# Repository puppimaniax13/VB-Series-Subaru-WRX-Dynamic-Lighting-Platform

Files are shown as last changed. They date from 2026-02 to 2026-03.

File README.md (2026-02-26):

# 2022+ Subaru WRX Dynamic LED Reflector Platform

Project Header

A full-stack hardware and software solution to replace static OEM rear reflectors with addressable, reactive LED modules. This project features a modular PCB designed for the VB chassis but adaptable to any 12V automotive lighting application.

## 🚀 Technical Overview
- **Mechanical:** Custom 3D-printed housings (Fusion 360) designed for OEM fitment.
- **Electrical:** Dual-layer custom PCB (KiCad) with 12V->5V buck regulation and signal filtering.
- **Software:** C++ Firmware (Arduino) utilizing **FastLED** for sequential animations and interrupt-driven brake logic.

## 🛠️ Hardware Stack
- **MCU:** ESP-32-S3-WROOM
- **LEDs:** WS2812B Addressable Strips
- **Design Tools:** KiCad 9.0, Autodesk Fusion 360, Adobe Lightroom (Documentation)
- **3D Printer:** Bambu Labs P1S, PLA & PETG

## 📂 Repository Structure
- `/Firmware`: Arduino source code (.ino)
- `/Hardware`: KiCad project files & PCB Schematics
- `/Mechanical`: .3mf files for printing
- `/Media`: High-res project photography

## 🖨️ 3D Printing
- When using the provided *.3mf* files please try not to adjust much.
- The filament used for the lens is as follows
  - Overture Transparent PETG
  - Bambu Translucent Grey PETG
  - Overture Transparent Red PETG

## ⚖️ License
Code/Firmware: This project is licensed under the **GNU GPLv3**. You are free to use and modify it, but any derivative works must also be open-sourced under the same license.

Hardware & Design (PCB/3D Models): Licensed under CC BY-NC-SA 4.0. Personal use is encouraged; commercial use or resale of these designs is strictly prohibited without prior authorization.

*Commercial use or resale of these designs is strictly prohibited.*

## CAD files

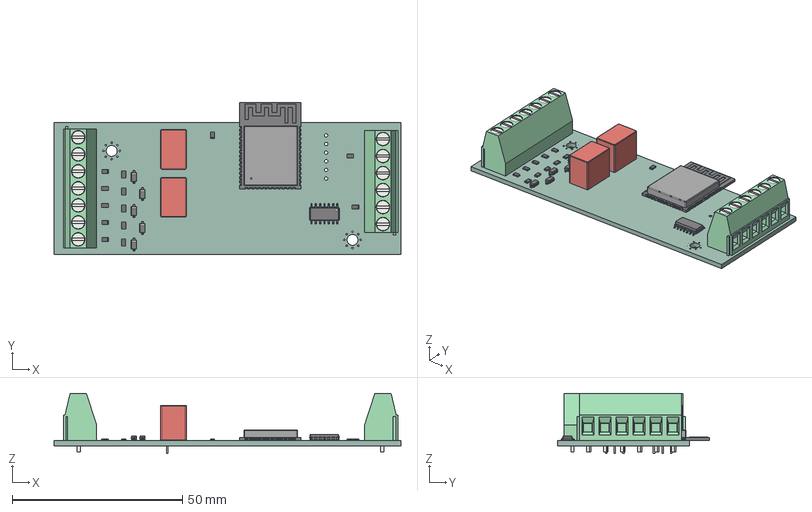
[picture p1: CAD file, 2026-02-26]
Hardware/CarLEDHub/CarLEDHub.step
102.0 x 44.7 x 17.7 mm
R_0805_2012Metric x 13
D_SOD-123 x 5
TerminalBlock_Phoenix_MKDS-1,5-6_1x06_P5.00mm_Horizontal
Converter_DCDC_TRACO_TSR-1_THT x 2
TerminalBlock_Phoenix_MKDS-1,5-7_1x07_P5.00mm_Horizontal
ESP32-S3-WROOM-1
SOIC-14_3.9x8.7mm_P1.27mm
CarLEDHub_PCB

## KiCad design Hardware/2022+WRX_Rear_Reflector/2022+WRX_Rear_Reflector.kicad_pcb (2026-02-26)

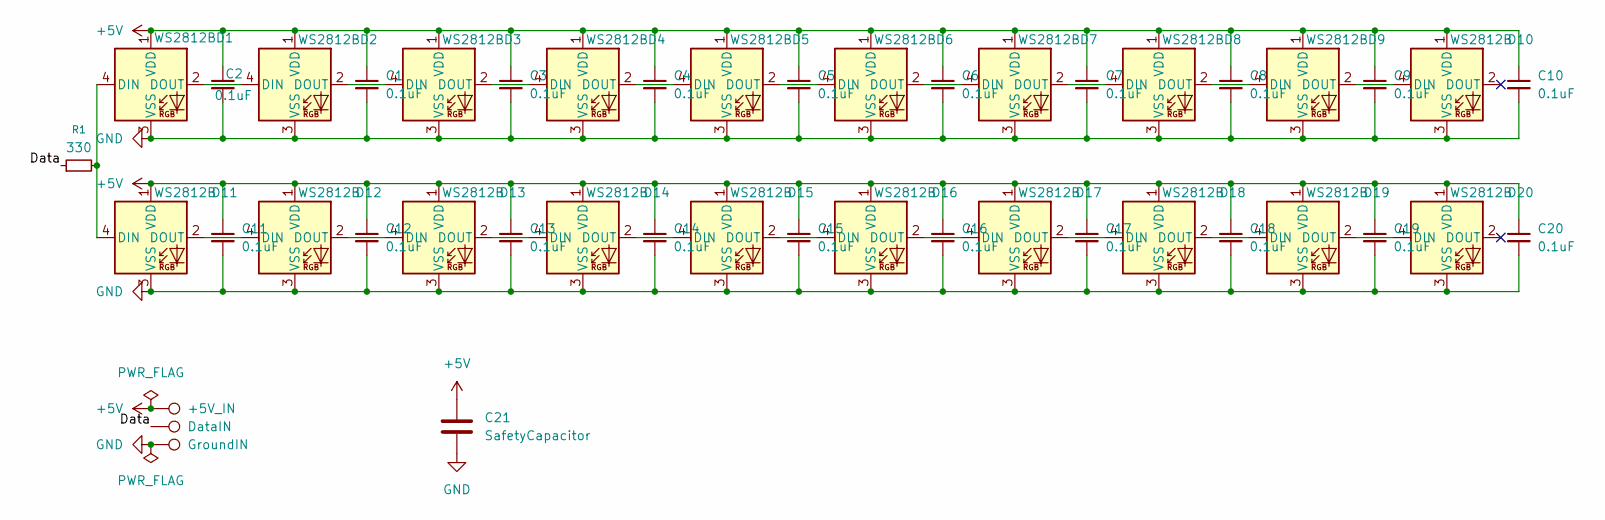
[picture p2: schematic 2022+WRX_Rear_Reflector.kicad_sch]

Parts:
C1, C2, C3, C4, C5, C6, C7, C8, C9, C10, C11, C12, C13, C14, C15, C16, C17, C18, C19, C20: 0.1uF; C_0504_1310Metric
C21: SafetyCapacitor; C_1206_3216Metric
D1, D2, D3, D4, D5, D6, D7, D8, D9, D10, D11, D12, D13, D14, D15, D16, D17, D18, D19, D20: WS2812B; LED_WS2812B_PLCC4_5.0x5.0mm_P3.2mm
R1: 330; R_0603_1608Metric
TP1: GroundIN; TestPoint_THTPad_D1.5mm_Drill0.7mm
TP2: DataIN; TestPoint_THTPad_D1.5mm_Drill0.7mm
TP3: +5V_IN; TestPoint_THTPad_D1.5mm_Drill0.7mm

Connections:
+5V: C1.1, C2.1, C3.1, C4.1, C5.1, C6.1, C7.1, C8.1, C9.1, C10.1, C11.1, C12.1, C13.1, C14.1, C15.1, C16.1, C17.1, C18.1, C19.1, C20.1, C21.1, D1.1 (VDD), D2.1 (VDD), D3.1 (VDD), D4.1 (VDD), D5.1 (VDD), D6.1 (VDD), D7.1 (VDD), D8.1 (VDD), D9.1 (VDD), D10.1 (VDD), D11.1 (VDD), D12.1 (VDD), D13.1 (VDD), D14.1 (VDD), D15.1 (VDD), D16.1 (VDD), D17.1 (VDD), D18.1 (VDD), D19.1 (VDD), D20.1 (VDD), TP3.1; also elsewhere on the board
/Data: R1.1, TP2.1; also elsewhere on the board
GND: C1.2, C2.2, C3.2, C4.2, C5.2, C6.2, C7.2, C8.2, C9.2, C10.2, C11.2, C12.2, C13.2, C14.2, C15.2, C16.2, C17.2, C18.2, C19.2, C20.2, C21.2, D1.3 (VSS), D2.3 (VSS), D3.3 (VSS), D4.3 (VSS), D5.3 (VSS), D6.3 (VSS), D7.3 (VSS), D8.3 (VSS), D9.3 (VSS), D10.3 (VSS), D11.3 (VSS), D12.3 (VSS), D13.3 (VSS), D14.3 (VSS), D15.3 (VSS), D16.3 (VSS), D17.3 (VSS), D18.3 (VSS), D19.3 (VSS), D20.3 (VSS), TP1.1; also elsewhere on the board
unnamed: D1.4 (DIN), D11.4 (DIN), R1.2
unnamed: D1.2 (DOUT), D2.4 (DIN)
unnamed: D2.2 (DOUT), D3.4 (DIN)
unnamed: D3.2 (DOUT), D4.4 (DIN)
unnamed: D4.2 (DOUT), D5.4 (DIN)
unnamed: D5.2 (DOUT), D6.4 (DIN)
unnamed: D6.2 (DOUT), D7.4 (DIN)
unnamed: D7.2 (DOUT), D8.4 (DIN)
unnamed: D8.2 (DOUT), D9.4 (DIN)
unnamed: D9.2 (DOUT), D10.4 (DIN)
unnamed: D11.2 (DOUT), D12.4 (DIN)
unnamed: D12.2 (DOUT), D13.4 (DIN)
unnamed: D13.2 (DOUT), D14.4 (DIN)
unnamed: D14.2 (DOUT), D15.4 (DIN)
unnamed: D15.2 (DOUT), D16.4 (DIN)
unnamed: D16.2 (DOUT), D17.4 (DIN)
unnamed: D17.2 (DOUT), D18.4 (DIN)
unnamed: D18.2 (DOUT), D19.4 (DIN)
unnamed: D19.2 (DOUT), D20.4 (DIN)

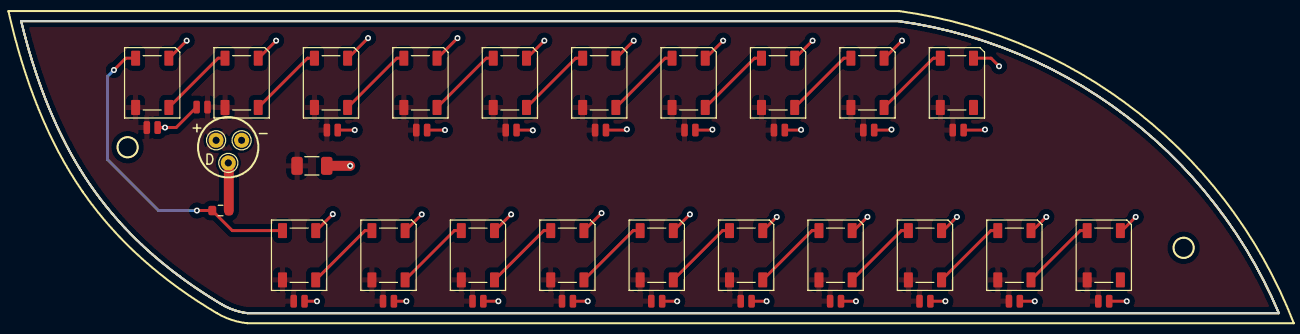
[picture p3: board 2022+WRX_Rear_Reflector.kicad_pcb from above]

Board: 2 copper layers, 125.1 x 29.0 mm, 45 parts (0 on the bottom side), 22 nets.

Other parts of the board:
+: +5V_IN; TestPoint_THTPad_D1.5mm_Drill0.7mm
-: GroundIN; TestPoint_THTPad_D1.5mm_Drill0.7mm
D: DataIN; TestPoint_THTPad_D1.5mm_Drill0.7mm

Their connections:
+5V: +.1; also elsewhere on the board
/Data: D.1; also elsewhere on the board
GND: -.1; also elsewhere on the board

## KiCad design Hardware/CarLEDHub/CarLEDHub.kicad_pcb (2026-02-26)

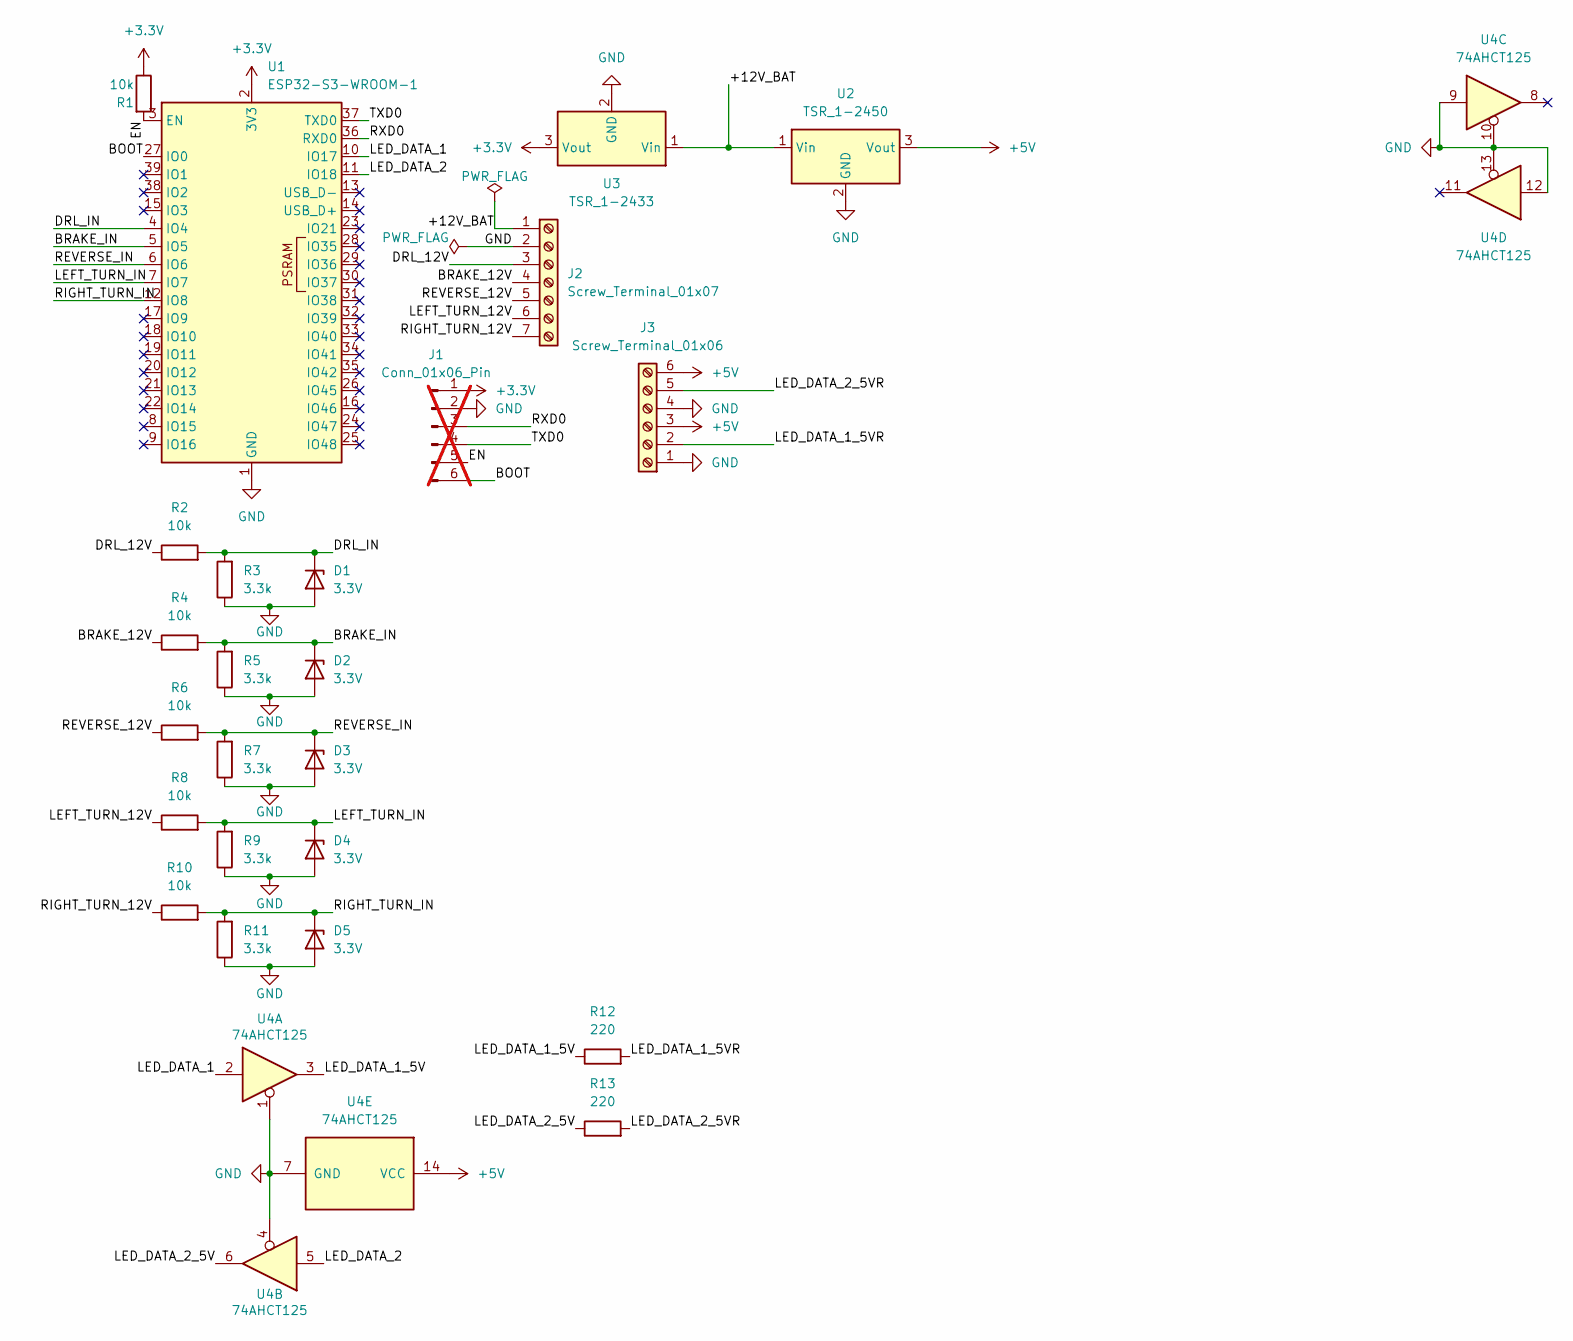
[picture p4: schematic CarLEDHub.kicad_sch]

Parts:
D1, D2, D3, D4, D5: 3.3V; D_SOD-123; LCSC C173413
J1: Conn_01x06_Pin; PinHeader_1x06_P2.54mm_Vertical; not fitted
J2: Screw_Terminal_01x07; TerminalBlock_Phoenix_MKDS-1,5-7_1x07_P5.00mm_Horizontal
J3: Screw_Terminal_01x06; TerminalBlock_Phoenix_MKDS-1,5-6_1x06_P5.00mm_Horizontal
R1, R2, R4, R6, R8, R10: 10k; R_0805_2012Metric
R3, R5, R7, R9, R11: 3.3k; R_0805_2012Metric
R12, R13: 220; R_0805_2012Metric
U1: ESP32-S3-WROOM-1; LCSC C2913576
U2: TSR_1-2450; Converter_DCDC_TRACO_TSR-1_THT; LCSC C5346721
U3: TSR_1-2433; Converter_DCDC_TRACO_TSR-1_THT; LCSC C5189115
U4: 74AHCT125; SOIC-14_3.9x8.7mm_P1.27mm

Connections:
+3.3V: J1.1, R1.1, U1.2 (3V3), U3.3 (Vout); also elsewhere on the board
+5V: J3.3, J3.6, U2.3 (Vout), U4.14 (VCC)
/+12V_BAT: J2.1, U2.1 (Vin), U3.1 (Vin)
/BOOT: J1.6, U1.27 (IO0); also elsewhere on the board
/BRAKE_12V: J2.4, R4.1
/BRAKE_IN: D2.1 (K), R4.2, R5.2, U1.5 (IO5)
/DRL_12V: J2.3, R2.1
/DRL_IN: D1.1 (K), R2.2, R3.2, U1.4 (IO4)
/EN: J1.5, R1.2, U1.3 (EN); also elsewhere on the board
/LED_DATA_1: U1.10 (IO17), U4.2
/LED_DATA_1_5V: R12.1, U4.3
/LED_DATA_1_5VR: J3.2, R12.2
/LED_DATA_2: U1.11 (IO18), U4.5
/LED_DATA_2_5V: R13.1, U4.6
/LED_DATA_2_5VR: J3.5, R13.2
/LEFT_TURN_12V: J2.6, R8.1
/LEFT_TURN_IN: D4.1 (K), R8.2, R9.2, U1.7 (IO7)
/REVERSE_12V: J2.5, R6.1
/REVERSE_IN: D3.1 (K), R6.2, R7.2, U1.6 (IO6)
/RIGHT_TURN_12V: J2.7, R10.1
/RIGHT_TURN_IN: D5.1 (K), R10.2, R11.2, U1.12 (IO8)
/RXD0: J1.3, U1.36 (RXD0); also elsewhere on the board
/TXD0: J1.4, U1.37 (TXD0); also elsewhere on the board
GND: D1.2 (A), D2.2 (A), D3.2 (A), D4.2 (A), D5.2 (A), J1.2, J2.2, J3.1, J3.4, R3.1, R5.1, R7.1, R9.1, R11.1, U1.1 (GND), U1.40 (GND), U1.41 (GND), U2.2 (GND), U3.2 (GND), U4.1, U4.4, U4.7 (GND), U4.9, U4.10, U4.12, U4.13; also elsewhere on the board

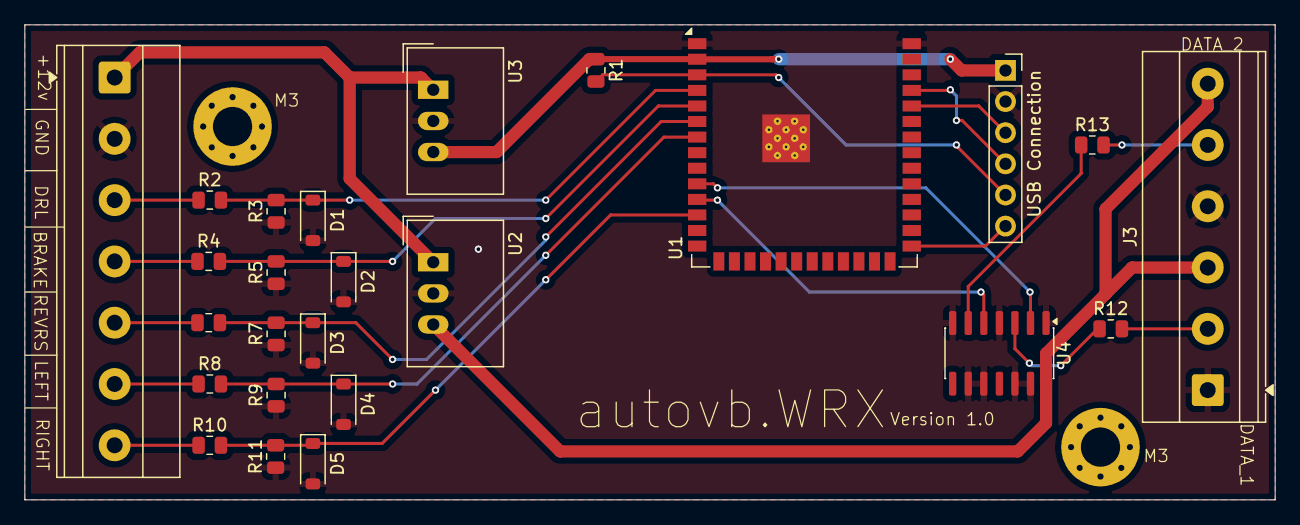
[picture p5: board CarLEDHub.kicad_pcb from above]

Board: 2 copper layers, 102.0 x 38.7 mm, 25 parts (0 on the bottom side), 24 nets.

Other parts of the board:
USB Connection: Conn_01x06_Pin; PinSocket_1x06_P2.54mm_Vertical

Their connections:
+3.3V: USB Connection.1; also elsewhere on the board
/BOOT: USB Connection.6; also elsewhere on the board
/EN: USB Connection.5; also elsewhere on the board
/RXD0: USB Connection.3; also elsewhere on the board
/TXD0: USB Connection.4; also elsewhere on the board
GND: USB Connection.2; also elsewhere on the board

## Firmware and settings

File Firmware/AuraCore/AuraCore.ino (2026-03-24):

#include <WiFi.h>
#include <ESPAsyncWebServer.h>
#include <FastLED.h>
#include <Preferences.h>
#include <ArduinoJson.h>   // Add "ArduinoJson" by Benoit Blanchon in Library Manager

#define MAX_LEDS        150
#define GPIO_DRL_IN     4
#define GPIO_BRAKE_IN   5
#define GPIO_TURN_L_IN  7
#define GPIO_TURN_R_IN  11
#define GPIO_DATA_1     9
#define GPIO_DATA_2     10

CRGB leds1[MAX_LEDS];
CRGB leds2[MAX_LEDS];

Preferences prefs;

struct Config {
  // Per-side brake colors
  CRGB brakeColorL;
  CRGB brakeColorR;
  // Per-side DRL colors
  CRGB drlColorL;
  CRGB drlColorR;
  // Per-side turn colors
  CRGB turnColorL;
  CRGB turnColorR;
  uint8_t  brightness;
  bool     invert;
  // DRL mode: 0=solid, 1=rainbow, 2=breathe, 3=chase
  uint8_t  drlMode;
  // Turn mode: 0=solid, 1=rainbow/spectral, 2=chase
  uint8_t  turnMode;
  // Brake mode: 0=solid, 1=F1 strobe, 2=2-tap, 3=pulse, 4=fade-in
  uint8_t  brakeMode;
  uint16_t wipeSpeed;
  int8_t   fineTune;
  uint16_t numLeds;
} settings;

unsigned long turnStartL = 0, turnStartR = 0;
unsigned long brakeStartTime = 0;
unsigned long lastBrakeRelease = 0;
bool isBraking      = false;
bool showroomActive = false;
bool isSyncing      = false;

AsyncWebServer server(80);

// ─── Helpers ──────────────────────────────────────────────────────────────────

String colorToHex(CRGB c) {
  char hex[7];
  sprintf(hex, "%02X%02X%02X", c.r, c.g, c.b);
  return String(hex);
}

CRGB hexToColor(const String& hex) {
  long val = strtol(hex.c_str(), NULL, 16);
  return CRGB((val >> 16) & 0xFF, (val >> 8) & 0xFF, val & 0xFF);
}

// ─── HTML (served over WiFi) ──────────────────────────────────────────────────
// NOTE: The full HTML is large. On ESP32-S3 this fits comfortably in flash.
// If flash is tight, move to PROGMEM or LittleFS.

String getHTML() {
  String h = "";

  // ── Head ──
  h += F("<!DOCTYPE html><html lang='en'><head>");
  h += F("<meta name='viewport' content='width=device-width,initial-scale=1.0,maximum-scale=1.0,user-scalable=no'>");
  h += F("<title>AuraCore v2.0</title>");
  h += F("<link rel='preconnect' href='https://fonts.googleapis.com'>");
  h += F("<link href='https://fonts.googleapis.com/css2?family=Rajdhani:wght@400;600;700&family=JetBrains+Mono:wght@400;700&display=swap' rel='stylesheet'>");

  // ── CSS ──
  h += F("<style>");
  h += F(":root{--bg:#080a0c;--surface:#0f1215;--card:#13171c;--border:#1e252e;--border2:#2a3340;--accent:#ff6a00;--accent2:#ffaa44;--blue:#3a8fff;--green:#2dff8e;--red:#ff3a3a;--amber:#ffbf00;--text:#cdd6e0;--muted:#4a5a6a;--dim:#232d38;}");
  h += F("*{box-sizing:border-box;margin:0;padding:0;-webkit-tap-highlight-color:transparent;}");
  h += F("body{background:var(--bg);color:var(--text);font-family:'Rajdhani',sans-serif;min-height:100vh;display:flex;justify-content:center;padding:0 0 40px 0;}");
  h += F(".app{width:100%;max-width:420px;padding:0 14px;}");

  // Header
  h += F(".header{padding:28px 0 18px;display:flex;align-items:center;justify-content:space-between;}");
  h += F(".logo-name{font-weight:700;font-size:1.6rem;letter-spacing:5px;color:#fff;line-height:1;}");
  h += F(".logo-name span{color:var(--accent);}");
  h += F(".logo-sub{font-family:'JetBrains Mono',monospace;font-size:0.55rem;color:var(--muted);letter-spacing:3px;margin-top:3px;}");
  h += F(".conn-badge{display:flex;align-items:center;gap:6px;background:var(--card);border:1px solid var(--border);border-radius:20px;padding:6px 12px;font-family:'JetBrains Mono',monospace;font-size:0.6rem;color:var(--green);cursor:pointer;}");
  h += F(".conn-dot{width:7px;height:7px;border-radius:50%;background:var(--green);box-shadow:0 0 8px var(--green);animation:pulse-dot 2s infinite;}");
  h += F("@keyframes pulse-dot{0%,100%{opacity:1;}50%{opacity:0.4;}}");
  h += F(".divider{height:1px;background:linear-gradient(90deg,transparent,var(--border2),transparent);margin:4px 0 18px;}");

  // Status bar
  h += F(".status-bar{display:grid;grid-template-columns:1fr 1fr 1fr 1fr;gap:8px;margin-bottom:18px;}");
  h += F(".sig{background:var(--card);border:1px solid var(--border);border-radius:10px;padding:10px 6px;text-align:center;transition:all 0.2s;position:relative;overflow:hidden;}");
  h += F(".sig::before{content:'';position:absolute;inset:0;opacity:0;transition:opacity 0.2s;}");
  h += F(".sig.active-sig{border-color:currentColor;}.sig.active-sig::before{opacity:0.07;background:currentColor;}");
  h += F(".sig-icon{font-size:1.1rem;line-height:1;margin-bottom:4px;}");
  h += F(".sig-label{font-family:'JetBrains Mono',monospace;font-size:0.48rem;color:var(--muted);text-transform:uppercase;letter-spacing:1px;}");
  h += F(".sig-state{font-family:'JetBrains Mono',monospace;font-size:0.55rem;font-weight:700;margin-top:2px;}");
  h += F(".sig.drl{color:var(--blue);}.sig.brk{color:var(--red);}.sig.tl{color:var(--amber);}.sig.tr{color:var(--amber);}");

  // Car / Card / Shared
  h += F(".car-section,.card{background:var(--card);border:1px solid var(--border);border-radius:18px;padding:18px;margin-bottom:14px;}");
  h += F(".section-label,.card-tag{font-family:'JetBrains Mono',monospace;font-size:0.55rem;color:var(--muted);letter-spacing:3px;text-transform:uppercase;}");
  h += F(".card-header{display:flex;justify-content:space-between;align-items:center;margin-bottom:16px;}");
  h += F(".card-tag{background:var(--dim);border-radius:6px;padding:3px 8px;}");
  h += F(".card-title{font-weight:700;font-size:0.85rem;letter-spacing:2px;text-transform:uppercase;}");

  // Range inputs
  h += F("input[type='range']{-webkit-appearance:none;appearance:none;width:100%;height:6px;border-radius:3px;background:var(--dim);outline:none;}");
  h += F("input[type='range']::-webkit-slider-thumb{-webkit-appearance:none;width:22px;height:22px;border-radius:50%;background:var(--accent);border:3px solid var(--bg);box-shadow:0 0 10px rgba(255,106,0,0.5);cursor:pointer;}");

  // Brightness
  h += F(".bright-row{display:flex;align-items:center;gap:14px;}");
  h += F(".bright-val{font-family:'JetBrains Mono',monospace;font-size:1.4rem;font-weight:700;color:#fff;min-width:54px;text-align:right;}");
  h += F(".bright-unit{font-size:0.7rem;color:var(--muted);font-weight:400;}");

  // Tabs
  h += F(".tabs{display:flex;gap:6px;flex-wrap:wrap;}");
  h += F(".tab{flex:1;min-width:0;padding:12px 6px;border-radius:10px;border:1px solid var(--border);background:var(--surface);color:var(--muted);font-family:'Rajdhani',sans-serif;font-weight:700;font-size:0.72rem;letter-spacing:1px;text-align:center;cursor:pointer;transition:all 0.15s;user-select:none;}");
  h += F(".tab:active{transform:scale(0.96);}.tab.active-tab{background:var(--dim);border-color:var(--accent);color:var(--accent);}");

  // Zone pickers
  h += F(".zone-row{display:grid;grid-template-columns:1fr 1fr;gap:10px;margin-top:14px;}");
  h += F(".zone-picker{display:flex;flex-direction:column;gap:6px;}");
  h += F(".zone-lbl{font-family:'JetBrains Mono',monospace;font-size:0.52rem;color:var(--muted);letter-spacing:2px;text-transform:uppercase;}");
  h += F("input[type='color']{width:100%;height:48px;border:1px solid var(--border2);border-radius:10px;background:var(--surface);cursor:pointer;padding:4px;}");
  h += F("input[type='number']{width:100%;height:48px;border:1px solid var(--border2);border-radius:10px;background:var(--surface);color:#fff;font-family:'JetBrains Mono',monospace;font-size:1rem;text-align:center;outline:none;}");

  // Rainbow badge
  h += F(".rainbow-badge{padding:14px;border-radius:10px;background:linear-gradient(90deg,#f00,#ff8000,#ff0,#0f0,#00f,#8b00ff);text-align:center;font-weight:700;font-size:0.75rem;letter-spacing:2px;color:#fff;text-shadow:1px 1px 4px #000;margin-top:14px;}");

  // Speed row
  h += F(".speed-row{display:flex;align-items:center;gap:10px;margin-top:8px;}");
  h += F(".speed-icon{font-size:1rem;}");

  // Showroom
  h += F(".btn-showroom{width:100%;padding:18px;border-radius:14px;border:none;background:var(--accent);color:#fff;font-family:'Rajdhani',sans-serif;font-weight:700;font-size:1rem;letter-spacing:3px;cursor:pointer;transition:all 0.2s;margin-bottom:14px;position:relative;overflow:hidden;}");
  h += F(".btn-showroom:active{transform:scale(0.98);}.btn-showroom.active{background:var(--red);box-shadow:0 0 20px rgba(255,58,58,0.35);}");

  // Tuner
  h += F(".tuner-toggle{display:flex;justify-content:space-between;align-items:center;cursor:pointer;user-select:none;padding:2px 0;}");
  h += F(".tuner-title{font-weight:700;font-size:0.85rem;letter-spacing:2px;color:var(--accent2);}");
  h += F(".tuner-arrow{font-size:0.8rem;color:var(--muted);transition:transform 0.25s;}.tuner-arrow.open{transform:rotate(180deg);}");
  h += F(".tuner-body{display:none;padding-top:18px;}.tuner-body.open{display:block;}");
  h += F(".field-row{margin-bottom:16px;}");
  h += F(".field-lbl{font-family:'JetBrains Mono',monospace;font-size:0.52rem;color:var(--muted);letter-spacing:2px;text-transform:uppercase;margin-bottom:8px;display:flex;justify-content:space-between;}");
  h += F(".field-lbl span{color:var(--accent);}");
  h += F(".toggle-row{display:flex;justify-content:space-between;align-items:center;background:var(--surface);border:1px solid var(--border);border-radius:12px;padding:14px 16px;margin-bottom:14px;}");
  h += F(".toggle-lbl{font-weight:600;font-size:0.8rem;letter-spacing:1px;}");
  h += F(".pill-btn{padding:8px 16px;border-radius:8px;border:1px solid var(--border2);background:var(--dim);color:var(--text);font-family:'Rajdhani',sans-serif;font-weight:700;font-size:0.7rem;letter-spacing:1px;cursor:pointer;transition:all 0.15s;}");
  h += F(".pill-btn.inverted{background:rgba(255,58,58,0.15);border-color:var(--red);color:var(--red);}");
  h += F(".btn-sync{width:100%;padding:15px;border-radius:12px;border:1px solid var(--amber);background:rgba(255,191,0,0.08);color:var(--amber);font-family:'Rajdhani',sans-serif;font-weight:700;font-size:0.85rem;letter-spacing:2px;cursor:pointer;margin-bottom:10px;}");
  h += F(".btn-reset{width:100%;padding:14px;border-radius:12px;border:1px solid #2a1515;background:#0e0808;color:#ff5555;font-family:'Rajdhani',sans-serif;font-weight:700;font-size:0.75rem;letter-spacing:2px;cursor:pointer;margin-top:8px;}");
  h += F(".debug-panel{display:none;font-family:'JetBrains Mono',monospace;font-size:0.6rem;color:#2dff8e;background:#000;border:1px solid #2dff8e;border-radius:10px;padding:12px;margin-top:14px;line-height:1.8;}");
  h += F("body::before{content:'';position:fixed;inset:0;background:repeating-linear-gradient(0deg,transparent,transparent 2px,rgba(0,0,0,0.03) 2px,rgba(0,0,0,0.03) 4px);pointer-events:none;z-index:999;}");
  h += F("</style></head><body><div class='app'>");

  // ── Header ──
  h += F("<div class='header'><div class='logo'>");
  h += F("<div class='logo-name'>AURA<span>CORE</span></div>");
  h += F("<div class='logo-sub'>LOGIC CONTROLLER · V2.0</div></div>");
  h += F("<div class='conn-badge' onclick='dCheck()'><div class='conn-dot'></div>ONLINE</div></div>");
  h += F("<div class='divider'></div>");

  // ── Status bar ──
  h += F("<div class='status-bar'>");
  h += F("<div class='sig drl' id='sigDRL'><div class='sig-icon'>💡</div><div class='sig-label'>DRL</div><div class='sig-state' id='sDRL'>OFF</div></div>");
  h += F("<div class='sig brk' id='sigBRK'><div class='sig-icon'>🔴</div><div class='sig-label'>BRAKE</div><div class='sig-state' id='sBRK'>OFF</div></div>");
  h += F("<div class='sig tl'  id='sigTL'> <div class='sig-icon'>◀</div>  <div class='sig-label'>LEFT</div> <div class='sig-state' id='sTL'>OFF</div></div>");
  h += F("<div class='sig tr'  id='sigTR'> <div class='sig-icon'>▶</div>  <div class='sig-label'>RIGHT</div><div class='sig-state' id='sTR'>OFF</div></div>");
  h += F("</div>");

  // ── Car diagram ──
  h += F("<div class='car-section'><div class='section-label' style='margin-bottom:14px;'>LED ZONE MAP</div>");
  h += F("<svg viewBox='0 0 300 160' xmlns='http://www.w3.org/2000/svg' style='width:100%;max-width:340px;display:block;margin:0 auto;'>");
  h += F("<defs><filter id='glow'><feGaussianBlur stdDeviation='2.5' result='blur'/><feMerge><feMergeNode in='blur'/><feMergeNode in='SourceGraphic'/></feMerge></filter>");
  h += F("<linearGradient id='bg' x1='0' y1='0' x2='0' y2='1'><stop offset='0%' stop-color='#1e252e'/><stop offset='100%' stop-color='#111820'/></linearGradient></defs>");
  h += F("<rect x='60' y='30' width='180' height='100' rx='16' fill='url(#bg)' stroke='#2a3340' stroke-width='1.5'/>");
  h += F("<rect x='90' y='18' width='120' height='28' rx='8' fill='#131a22' stroke='#2a3340' stroke-width='1'/>");
  h += F("<rect x='94' y='20' width='112' height='24' rx='6' fill='#0d1520' opacity='0.8'/>");
  h += F("<circle cx='100' cy='130' r='14' fill='#0a0e14' stroke='#2a3340' stroke-width='2'/><circle cx='100' cy='130' r='7' fill='#13171c' stroke='#1e252e' stroke-width='1'/>");
  h += F("<circle cx='200' cy='130' r='14' fill='#0a0e14' stroke='#2a3340' stroke-width='2'/><circle cx='200' cy='130' r='7' fill='#13171c' stroke='#1e252e' stroke-width='1'/>");
  // Left rear zone
  h += "<rect x='62' y='45' width='18' height='50' rx='5' fill='#" + colorToHex(settings.brakeColorL) + "22' stroke='#" + colorToHex(settings.brakeColorL) + "' stroke-width='1.5' filter='url(#glow)'/>";
  h += F("<text x='71' y='100' font-family='monospace' font-size='8' fill='#4a5a6a' text-anchor='middle'>L</text>");
  // Right rear zone
  h += "<rect x='220' y='45' width='18' height='50' rx='5' fill='#" + colorToHex(settings.brakeColorR) + "22' stroke='#" + colorToHex(settings.brakeColorR) + "' stroke-width='1.5' filter='url(#glow)'/>";
  h += F("<text x='229' y='100' font-family='monospace' font-size='8' fill='#4a5a6a' text-anchor='middle'>R</text>");
  h += F("<rect x='120' y='58' width='60' height='8' rx='3' fill='#0a1018' stroke='#1e252e' stroke-width='1'/>");
  h += F("<rect x='120' y='74' width='60' height='8' rx='3' fill='#0a1018' stroke='#1e252e' stroke-width='1'/>");
  h += F("<rect x='120' y='90' width='60' height='8' rx='3' fill='#0a1018' stroke='#1e252e' stroke-width='1'/>");
  h += F("<text x='150' y='150' font-family='monospace' font-size='7' fill='#3a4a5a' text-anchor='middle'>REAR VIEW</text>");
  h += F("</svg>");
  h += F("<div style='display:flex;gap:10px;margin-top:12px;justify-content:center;'>");
  h += F("<div style='display:flex;align-items:center;gap:5px;'><div style='width:10px;height:10px;border-radius:2px;background:#ff3a3a;box-shadow:0 0 6px #ff3a3a;'></div><span style='font-family:JetBrains Mono,monospace;font-size:0.55rem;color:#4a5a6a;'>BRAKE/DRL</span></div>");
  h += F("<div style='display:flex;align-items:center;gap:5px;'><div style='width:10px;height:10px;border-radius:2px;background:#ffbf00;box-shadow:0 0 6px #ffbf00;'></div><span style='font-family:JetBrains Mono,monospace;font-size:0.55rem;color:#4a5a6a;'>TURN SIGNAL</span></div>");
  h += F("</div></div>");

  // ── Brightness ──
  int bPct = round((settings.brightness / 255.0) * 100);
  h += F("<div class='card'><div class='card-header'><div class='card-title'>BRIGHTNESS</div><div class='card-tag' id='bPct'>");
  h += String(bPct); h += F("%</div></div><div class='bright-row'>");
  h += "<input type='range' min='0' max='255' value='" + String(settings.brightness) + "' oninput='uB(this.value)' onchange=\"fetch('/bright?val='+this.value)\" style='flex:1;'>";
  h += "<div class='bright-val' id='bVal'>" + String(settings.brightness) + "<span class='bright-unit'> / 255</span></div>";
  h += F("</div></div>");

  // ── Brake ──
  String bm[5] = {"active-tab","","","",""};
  bm[settings.brakeMode] = "active-tab";
  h += F("<div class='card'><div class='card-header'><div class='card-title'>BRAKE LIGHT</div><div class='card-tag'>REAR</div></div>");
  h += F("<div class='tabs'>");
  h += "<div class='tab " + bm[0] + "' onclick='sB(0)' id='b0'>SOLID</div>";
  h += "<div class='tab " + bm[1] + "' onclick='sB(1)' id='b1'>F1</div>";
  h += "<div class='tab " + bm[2] + "' onclick='sB(2)' id='b2'>2-TAP</div>";
  h += "<div class='tab " + bm[3] + "' onclick='sB(3)' id='b3'>PULSE</div>";
  h += "<div class='tab " + bm[4] + "' onclick='sB(4)' id='b4'>FADE</div>";
  h += F("</div><div class='zone-row'>");
  h += "<div class='zone-picker'><div class='zone-lbl'>LEFT SIDE</div><input type='color' id='bColorL' value='#" + colorToHex(settings.brakeColorL) + "' onchange=\"sendColor('/bcolor_l',this.value)\"></div>";
  h += "<div class='zone-picker'><div class='zone-lbl'>RIGHT SIDE</div><input type='color' id='bColorR' value='#" + colorToHex(settings.brakeColorR) + "' onchange=\"sendColor('/bcolor_r',this.value)\"></div>";
  h += F("</div><div style='margin-top:10px;text-align:right;'><span onclick='syncBrakeColors()' style='font-family:JetBrains Mono,monospace;font-size:0.55rem;color:#4a5a6a;cursor:pointer;text-decoration:underline;text-underline-offset:3px;'>SYNC L/R</span></div></div>");

  // ── DRL ──
  String dm[4] = {"","","",""};
  dm[settings.drlMode] = "active-tab";
  bool dSolid = (settings.drlMode == 0);
  h += F("<div class='card'><div class='card-header'><div class='card-title'>DRL</div><div class='card-tag'>DAYTIME</div></div>");
  h += F("<div class='tabs'>");
  h += "<div class='tab " + dm[0] + "' onclick=\"sM('d','solid')\" id='tDS'>SOLID</div>";
  h += "<div class='tab " + dm[1] + "' onclick=\"sM('d','rainbow')\" id='tDR'>RAINBOW</div>";
  h += "<div class='tab " + dm[2] + "' onclick=\"sM('d','breathe')\" id='tDB'>BREATHE</div>";
  h += "<div class='tab " + dm[3] + "' onclick=\"sM('d','chase')\" id='tDC'>CHASE</div>";
  h += F("</div>");
  h += "<div id='dSC' style='display:" + String(dSolid ? "block" : "none") + ";'>";
  h += F("<div class='zone-row'>");
  h += "<div class='zone-picker'><div class='zone-lbl'>LEFT SIDE</div><input type='color' value='#" + colorToHex(settings.drlColorL) + "' onchange=\"sendColor('/drl_l',this.value)\"></div>";
  h += "<div class='zone-picker'><div class='zone-lbl'>RIGHT SIDE</div><input type='color' value='#" + colorToHex(settings.drlColorR) + "' onchange=\"sendColor('/drl_r',this.value)\"></div>";
  h += F("</div></div>");
  h += "<div id='dRC' style='display:" + String(!dSolid ? "block" : "none") + ";'><div class='rainbow-badge'>MODE ACTIVE</div></div></div>";

  // ── Turn ──
  String tm[3] = {"","",""};
  tm[settings.turnMode] = "active-tab";
  bool tSolid = (settings.turnMode == 0);
  h += F("<div class='card'><div class='card-header'><div class='card-title'>TURN SIGNAL</div><div class='card-tag'>SEQUENTIAL</div></div>");
  h += F("<div class='tabs'>");
  h += "<div class='tab " + tm[0] + "' onclick=\"sM('t','solid')\" id='tTS'>SOLID</div>";
  h += "<div class='tab " + tm[1] + "' onclick=\"sM('t','rainbow')\" id='tTR'>SPECTRAL</div>";
  h += "<div class='tab " + tm[2] + "' onclick=\"sM('t','chase')\" id='tTC'>CHASE</div>";
  h += F("</div>");
  h += "<div id='tSC' style='display:" + String(tSolid ? "block" : "none") + ";'>";
  h += F("<div class='zone-row'>");
  h += "<div class='zone-picker'><div class='zone-lbl'>LEFT TURN</div><input type='color' value='#" + colorToHex(settings.turnColorL) + "' onchange=\"sendColor('/tcolor_l',this.value)\"></div>";
  h += "<div class='zone-picker'><div class='zone-lbl'>RIGHT TURN</div><input type='color' value='#" + colorToHex(settings.turnColorR) + "' onchange=\"sendColor('/tcolor_r',this.value)\"></div>";
  h += F("</div></div>");
  h += "<div id='tRC' style='display:" + String(!tSolid ? "block" : "none") + ";'><div class='rainbow-badge'>SPECTRAL WIPE ACTIVE</div></div>";
  // Wipe speed
  h += F("<div style='margin-top:16px;'><div class='field-lbl'>WIPE SPEED <span id='wipeVal'>");
  h += String(settings.wipeSpeed); h += F("ms</span></div>");
  h += F("<div class='speed-row'><span class='speed-icon'>🐇</span>");
  h += "<input type='range' min='10' max='80' value='" + String(settings.wipeSpeed) + "' oninput=\"document.getElementById('wipeVal').innerText=this.value+'ms'\" onchange=\"fetch('/wipe?val='+this.value)\" style='flex:1;'>";
  h += F("<span class='speed-icon'>🐢</span></div></div></div>");

  // ── Showroom ──
  h += F("<button class='btn-showroom' id='srBtn' onclick='tS()'>&#9654; ACTIVATE SHOWROOM</button>");
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
void loop() {
  if (showroomActive) {
    fill_rainbow(leds1, settings.numLeds, millis() / 20, 10);
    fill_rainbow(leds2, settings.numLeds, millis() / 20, 10);
  } else {
    CRGB* leftStrip  = settings.invert ? leds2 : leds1;
    CRGB* rightStrip = settings.invert ? leds1 : leds2;
    handleSideLogic(GPIO_TURN_L_IN, leftStrip,  settings.turnColorL, settings.drlColorL, settings.brakeColorL, turnStartL);
    handleSideLogic(GPIO_TURN_R_IN, rightStrip, settings.turnColorR, settings.drlColorR, settings.brakeColorR, turnStartR);
  }
  FastLED.show();
}

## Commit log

2026-02-26 Add KiCad for Hub
    LEDHub that is the brains of the operation.
    [CarLEDHub.kicad_pcb, CarLEDHub.kicad_sch, CarLEDHub.step]
2026-02-26 Added Rear Reflector PCB (WIP)
    WORK IN PROGRESS
    [2022+WRX_Rear_Reflector.kicad_pcb, 2022+WRX_Rear_Reflector.kicad_sch]
2026-03-01 Update AuraCore v1.4
    Added the ability to set how many LED's and brought back the sleep times.
2026-03-24 AuraCore.ino v2
    Reworked the design with the help of Claude.ai. Still have more changes to come in the design.
    [AuraCore.ino]
